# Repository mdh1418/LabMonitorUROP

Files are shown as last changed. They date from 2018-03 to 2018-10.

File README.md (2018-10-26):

# LabMonitor

UROP with Prof. Joe Steinmeyer to bring out a low cost and small footprint system to monitor environmental data within a laboratory setting.

## Getting Started

For this project, we are using the ESP32 (https://www.espressif.com/en/products/hardware/esp32/overview), the BME680 environmental sensor (https://cdn-shop.adafruit.com/product-files/3660/BME680.pdf), as well as a customized PCB for a minimal barebones setup. The ESP32 and BME680 are interfaced using I2C.

### Setup (WITHOUT PCB)

Materials
* ESP32-DevKitC (https://www.espressif.com/en/products/hardware/esp32-devkitc/overview)
* Adafruit BME680 (https://learn.adafruit.com/adafruit-bme680-humidity-temperature-barometic-pressure-voc-gas)
* Jumper cables
* USB to MicroUSB cable
* Breadboard

After installing the software listed below in the Software section to program the ESP32-DevKitC with Arduino, simply follow the hookup guide outlined in the Adafruit tutorial linked above in the materials list.

Materials
* ESP-Wroom-32 (https://www.espressif.com/en/products/hardware/esp-wroom-32/overview)
* BME680 (https://www.bosch-sensortec.com/bst/products/all_products/bme680)
* Sparkfun FTDI (https://www.sparkfun.com/products/9716)
* Customized PCB
* 2 Buttons (Reset and Prgm)
* Wires
* Breadboard

After installing the software listed below in the Software section to program the ESP-Wroom-32, (

Notes
* Use 3.3V on the FTDI so cut the 5V connection and solder the 3.3V connection
* To program the ESP-Wroom-32, press Reset, press Prgm, release Reset, and release Prgm and upload the sketch
* When using wifi, the FTDI driver cannot supply enough current, so power using batteries or a lab supply

### Software

Programming the ESP32 with Arduino
https://github.com/espressif/arduino-esp32

BME680 Driver
https://github.com/BoschSensortec/BME680_driver

KiCad (If customizing PCB)
http://kicad-pcb.org/

### References
http://esp32.net/
https://www.espressif.com/sites/default/files/documentation/esp32_hardware_design_guidelines_en.pdf
https://www.espressif.com/sites/default/files/documentation/esp-wroom-32_datasheet_en.pdf
https://3.bp.blogspot.com/-zyGHuqISKPs/WMx4MWPAZOI/AAAAAAAAAMw/xxDcpwVSq0garkCG5n8yQfn4X7r94zMHACLcB/s1600/ESP%2B32%2BSchematic.PNG
https://cdn-shop.adafruit.com/product-files/3660/BME680.pdf
https://learn.adafruit.com/adafruit-bme680-humidity-temperature-barometic-pressure-voc-gas/arduino-wiring-test
https://www.14core.com/wiring-and-flashing-programming-esp-32-esp32s-with-usb-ttl-uart/
https://github.com/sparkfun/SparkFun-KiCad-Libraries
https://www.wayneandlayne.com/blog/2013/02/27/kicad-tutorial-gerber-file-generation/
https://techtutorialsx.com/2017/04/24/esp32-publishing-messages-to-mqtt-topic/

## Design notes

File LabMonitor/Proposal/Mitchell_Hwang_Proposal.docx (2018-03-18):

Mitchell Hwang

UROP Faculty Supervisor: Joe Steinmeyer

Term: Spring 2018

Location: 38-500

2/6/2018

Affordable Distributed Lab Environment Sensors 2018

Project Overview

For the 2018 spring term, I will be working directly under Professor Steinmeyer in 38-500 for the development of an Affordable Distributed Lab Environment Sensors system (ADLES). The system will be built under the supervision of Professor Steinmeyer. The system seeks to save researchers who are running experiments where environmental factors can drastically alter data from spending weeks not realizing that the difference was due to a change in temperature for example. More often than not, environmental factors such as temperature, humidity, pressure, and relative gas levels are not taken into consideration when performing experiments in labs. As a result, experiments following the same procedures can end up with different data results. The high level architecture of the system will comprise of a main server communicating via Wi-Fi with several battery-powered modules comprised of an ESP32 SoC as well as the BME680 environmental sensor. These modules will frequently update the server with their local sensor readings which will then be integrated in a graphical user interface that researchers can monitor. Because affordability and low footprint are big concerns, custom made PCBs will be used for these modules. The ADLES system looks to expedite the experimental process and aid researchers in determining the causes for any fluctuations in data.

Personal Role & Responsibilities

I will be working under the discretion of Prof. Steinmeyer in 38-500. With his guidance and executive decisions, I will research the necessary components as well as bring out the entire end-to-end system. This includes looking into which chips and sensors would make the system fully functional, designing and minimizing the footprints, as well as creating the web interface through which the sensor data can be monitored.

Goals.

Personally, I want to increase my experience with bringing out end-to-end systems as well as put my systems designing and engineering abilities accumulated over the years at MIT to the test. I also wish to experience working independently with guidance from an experienced professor, and I hope to broaden my own capabilities.

Personal Statement

I have taken interested in this UROP mainly because of its concept, because being able to cut down the time researchers spend debugging their experiments at a low cost can definitely provide a positive impact towards the research community. I hope to learn many skills from Professor Steinmeyer as well as improve my own design decision skills to be able to build better systems in the future.

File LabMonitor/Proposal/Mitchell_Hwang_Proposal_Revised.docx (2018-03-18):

Mitchell Hwang

UROP Faculty Supervisor: Joe Steinmeyer

Term: Spring 2018

Location: 38-500

2/9/2018

Affordable Distributed Lab Environment Sensors 2018

Project Overview

For the 2018 spring term, I will be working directly under Professor Steinmeyer in 38-500 for the development of an Affordable Distributed Lab Environment Sensor system (ADLES). The system will be built under the supervision of Professor Steinmeyer. The purpose of the project is several-fold: First it seeks to provide a means of measuring small changes in environmental characteristics including (but not limited to) humidity, temperature, pressure, and various gas concentrations over the scale of inches within environmental chambers for biological experiments via a distributed sensor network. This will be enabled by developing inexpensive small boards which can unobtrusively be placed within confined spaces such as incubators, biological containment chambers, and other locations. The goal is to easily provide researchers with more quantifiable data at higher spatial and temporal resolutions than is currently accessible for the purpose of aiding in supplementing experimental results. A second main goal is to develop a distributed system using the relatively new ESP32 SOC hardware produced by Espressif. The high level architecture of the system will comprise of a main server communicating via Wi-Fi, Bluetooth, or some other form of communication in the ISM band with several battery-powered modules comprised of an ESP32 SOC as well as the BME680 environmental sensor. These modules will frequently update the server with their local sensor readings which will then be integrated in a graphical user interface that researchers can monitor. Because affordability and low footprint are big concerns, custom made PCBs will be used for these modules. The ADLES system looks to expedite the experimental process and aid researchers in determining the causes for any fluctuations in data.

Personal Role & Responsibilities

I will be working under the discretion of Prof. Steinmeyer in 38-500. With his guidance and executive decisions, I will research the necessary components as well as bring out the entire end-to-end system. This includes looking into which chips and sensors would make the system fully functional, designing and minimizing the footprints, as well as creating the web interface through which the sensor data can be monitored.

Goals.

Personally, I want to increase my experience with bringing out end-to-end systems as well as put my systems designing and engineering abilities accumulated over the years at MIT to the test. I also wish to experience working independently with guidance from an experienced professor, and I hope to broaden my own capabilities.

Personal Statement

I have taken interested in this UROP mainly because of its concept, because being able to cut down the time researchers spend debugging their experiments at a low cost can definitely provide a positive impact towards the research community. I hope to learn many skills from Professor Steinmeyer as well as improve my own design decision skills to be able to build better systems in the future.

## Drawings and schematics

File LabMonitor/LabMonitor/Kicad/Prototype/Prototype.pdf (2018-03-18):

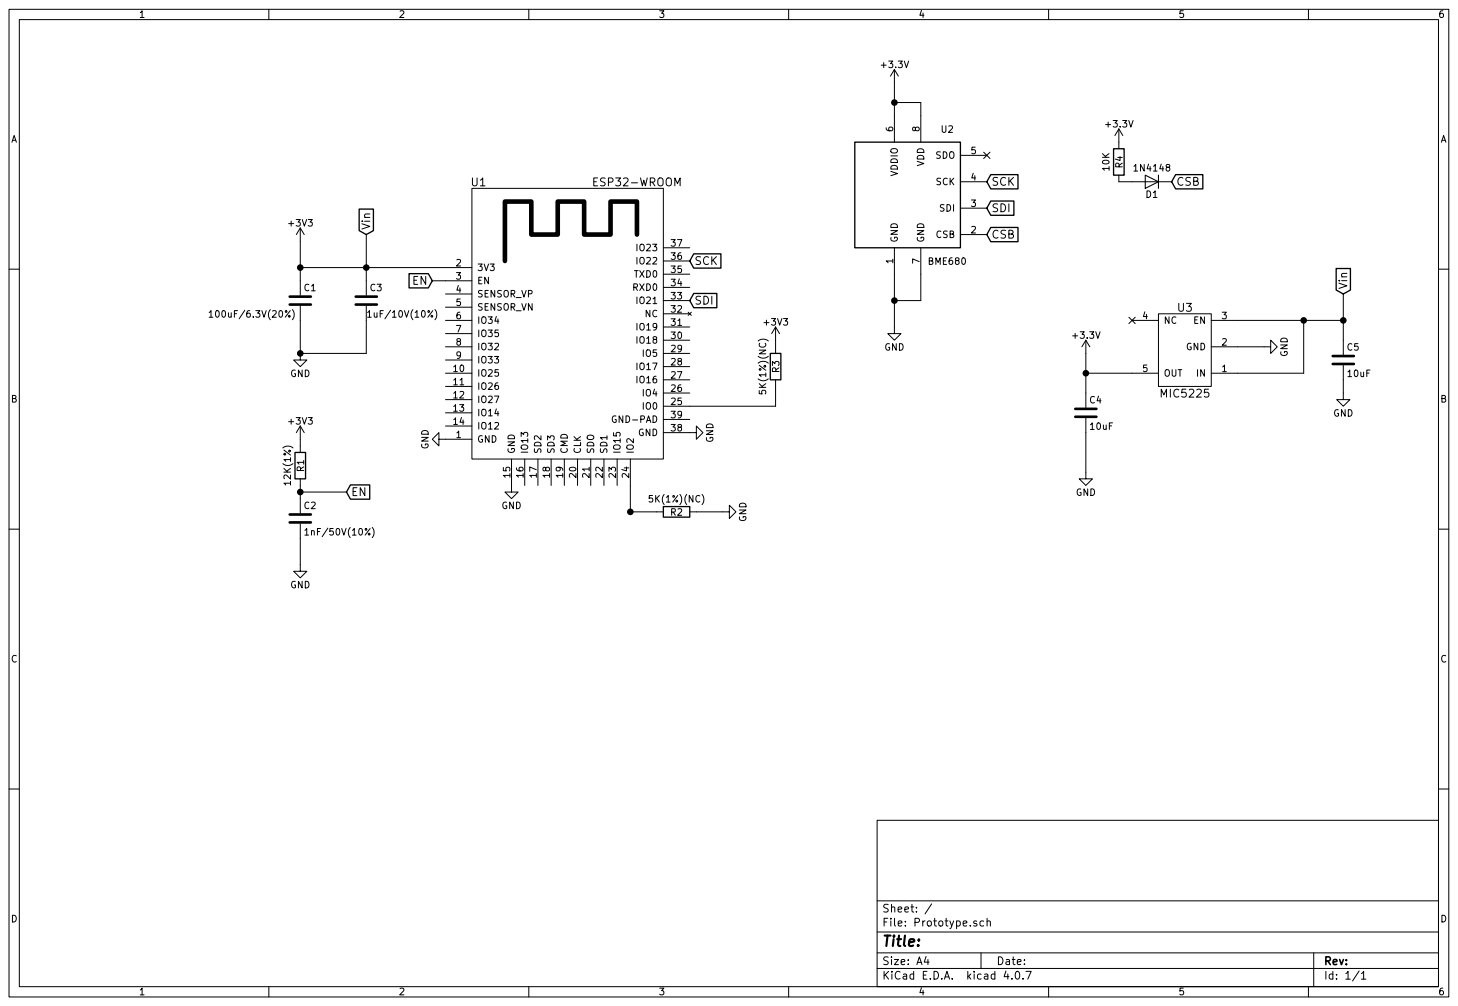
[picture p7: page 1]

1 CSB 2 SDI 3 SCK 4 SDO 5 VDDIO

File: Prototype.sch Sheet: / GND 1

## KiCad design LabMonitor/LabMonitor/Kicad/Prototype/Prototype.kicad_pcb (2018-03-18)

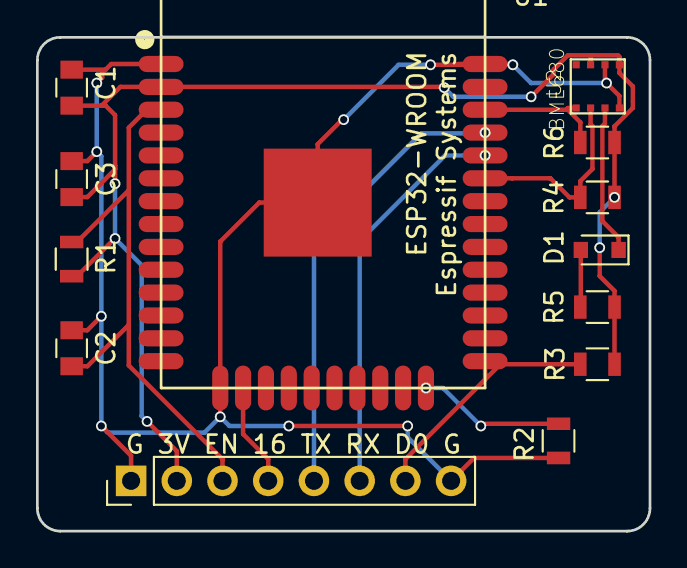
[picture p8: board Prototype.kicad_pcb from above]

Board: 2 copper layers, 34.0 x 27.4 mm, 13 parts (0 on the bottom side), 12 nets.

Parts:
C1: 100uF/6.3V(20%); C_0805
C2: 1nF/50V(10%); C_0805
C3: 1uF/10V(10%); C_0805
D1: 1N4148; D_0805
G 3V EN 16 TX RX D0 G: Conn_01x08; Socket_Strip_Straight_1x08_Pitch2.54mm
R1: 12K(1%); R_0805
R2, R3: 5K(1%)(NC); R_0805
R4, R5, R6: 10K; R_0805
U1: ESP32-WROOM
U2: BME680

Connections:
16: G 3V EN 16 TX RX D0 G.4, U1.16
+3V3: C1.1, C3.1, G 3V EN 16 TX RX D0 G.2, R1.1, R3.1, R4.1, R5.1, R6.1, U1.2, U2.6, U2.8
CSB: D1.1, U2.2
D0: G 3V EN 16 TX RX D0 G.7, R3.2, U1.25
EN: C2.1, G 3V EN 16 TX RX D0 G.3, R1.2, U1.3
GND: C1.2, C2.2, C3.2, G 3V EN 16 TX RX D0 G.1, G 3V EN 16 TX RX D0 G.8, R2.1, U1.1, U1.15, U1.38, U1.39, U2.1, U2.7
unnamed: D1.2, R5.2
unnamed: R2.2, U1.24
RX: G 3V EN 16 TX RX D0 G.6, U1.34
SCK: R6.2, U1.36, U2.4
SDI: R4.2, U1.33, U2.3
TX: G 3V EN 16 TX RX D0 G.5, U1.35

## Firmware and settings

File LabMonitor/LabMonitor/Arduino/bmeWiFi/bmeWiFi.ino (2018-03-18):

#include <WiFi.h>
#include <Wire.h>
#include <SPI.h>
#include <Adafruit_Sensor.h>
#include "Adafruit_BME680.h"

#define BME_SCK 22
#define BME_SDA 21

#define SEALEVELPRESSURE_HPA (1013.25)

const char* ssid = "EECS-MTL-RLE";
const char* password = "";

WiFiServer server(80);

Adafruit_BME680 bme; // I2C

void setup() {
  Serial.begin(115200);
  pinMode(5, OUTPUT);
  while (!Serial);
  Serial.print("Connecting to ");
  Serial.println(ssid);
  WiFi.begin(ssid, password);

  while (WiFi.status() != WL_CONNECTED){
    delay(500);
    Serial.print(".");
  }
  Serial.println("");
  Serial.println("WiFi connected.");
  Serial.println("IP address: ");
  Serial.println(WiFi.localIP());

  server.begin();
  
  Serial.println(F("BME680 test"));

  if (!bme.begin()) {
    Serial.println("Could not find a valid BME680 sensor, check wiring!");
    while (1);
  }

  // Set up oversampling and filter initialization
  bme.setTemperatureOversampling(BME680_OS_8X);
  bme.setHumidityOversampling(BME680_OS_2X);
  bme.setPressureOversampling(BME680_OS_4X);
  bme.setIIRFilterSize(BME680_FILTER_SIZE_3);
  bme.setGasHeater(320, 150); // 320*C for 150 ms
}

void loop() {
  WiFiClient client = server.available();   // listen for incoming clients

  if (client) {                             // if you get a client,
    Serial.println("New Client.");           // print a message out the serial port
    String currentLine = "";                // make a String to hold incoming data from the client
    while (client.connected()) {            // loop while the client's connected
      if (client.available()) {             // if there's bytes to read from the client,
        char c = client.read();             // read a byte, then
        Serial.write(c);                    // print it out the serial monitor
        if (c == '\n') {                    // if the byte is a newline character

          // if the current line is blank, you got two newline characters in a row.
          // that's the end of the client HTTP request, so send a response:
          if (currentLine.length() == 0) {
            // HTTP headers always start with a response code (e.g. HTTP/1.1 200 OK)
            // and a content-type so the client knows what's coming, then a blank line:
            client.println("HTTP/1.1 200 OK");
            client.println("Content-type:text/html");
            client.println();

            // the content of the HTTP response follows the header:
            client.print("Click <a href=\"/H\">here</a> to turn the LED on pin 5 on.<br>");
            client.print("Click <a href=\"/L\">here</a> to turn the LED on pin 5 off.<br>");

            // The HTTP response ends with another blank line:
            client.println();
            // break out of the while loop:
            break;
          } else {    // if you got a newline, then clear currentLine:
            currentLine = "";
          }
        } else if (c != '\r') {  // if you got anything else but a carriage return character,
          currentLine += c;      // add it to the end of the currentLine
        }

        // Check to see if the client request was "GET /H" or "GET /L":
        if (currentLine.endsWith("GET /H")) {
          digitalWrite(5, HIGH);               // GET /H turns the LED on
        }
        if (currentLine.endsWith("GET /L")) {
          digitalWrite(5, LOW);                // GET /L turns the LED off
        }
      }
    }
    // close the connection:
    client.stop();
    Serial.println("Client Disconnected.");
  }
  if (! bme.performReading()) {
    Serial.println("Failed to perform reading :(");
    return;
  }
  Serial.print("Temperature = ");
  Serial.print(bme.temperature);
  Serial.println(" *C");

  Serial.print("Pressure = ");
  Serial.print(bme.pressure / 100.0);
  Serial.println(" hPa");

  Serial.print("Humidity = ");
  Serial.print(bme.humidity);
  Serial.println(" %");

  Serial.print("Gas = ");
  Serial.print(bme.gas_resistance / 1000.0);
  Serial.println(" KOhms");

  Serial.print("Approx. Altitude = ");
  Serial.print(bme.readAltitude(SEALEVELPRESSURE_HPA));
  Serial.println(" m");

  Serial.println();
  delay(2000);

}

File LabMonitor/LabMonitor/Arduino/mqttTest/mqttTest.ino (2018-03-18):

#include <WiFi.h>
#include <PubSubClient.h>

const char* ssid = "EECS-ConfRooms";
const char* password = "";
const char* mqttServer = "m14.cloudmqtt.com";
const int mqttPort = 10247;
const char* mqttUser = "vgocvszf";
const char* mqttPassword = "oqZodFHab_cp";

WiFiClient espClient;
PubSubClient client(espClient);

void setup() {
  // put your setup code here, to run once:
  Serial.begin(115200);
  WiFi.disconnect();
  WiFi.begin(ssid, password);

  while(WiFi.status() != WL_CONNECTED){
    delay(500);
    Serial.println("Connecting to WiFi...");
  }

  Serial.println("Connected to the WiFi network");

  client.setServer(mqttServer, mqttPort);

  while (!client.connected()){
    Serial.println("Connecting to MQTT...");

    if (client.connect("ESP32Client", mqttUser, mqttPassword)){

      Serial.println("connected");

    } else{
      Serial.print("failed with state ");
      Serial.print(client.state());
      delay(2000);
    }
  }

  client.publish("esp/test", "Hello from ESP32");
}

void loop() {
  // put your main code here, to run repeatedly:
  client.loop();
}

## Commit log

2018-03-18 Added all relevant files
    [FixBMEFootpring.kicad_pcb, Prototype 3.sch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]
2018-03-18 added kicad and bme-micropython
    [1593K_Enclosure.kicad_pcb, 1593K_Enclosure.sch, Arduino_As_Uno.kicad_pcb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]
2018-04-01 Testing image wiki upload
    [_saved_Prototype.sch]
